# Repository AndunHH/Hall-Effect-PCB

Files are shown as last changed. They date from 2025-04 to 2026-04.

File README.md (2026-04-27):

# Hall-Effect-PCB
Repo to store PCB files for the hall effect sensor space mouse 

This repo is based on the work by Michael Roth:
https://www.printables.com/model/1063960-cad-mouse-spacemouse-using-hall-effect-sensors-w-p

Open the file in KiCad.

## Modifications
Added connectors for possible connection of keys, encoders and LEDs. The actual housing do not fit in a close space mouse, but it's fine for a first test or to solder the wires directly. 

Here a 3d rendering:

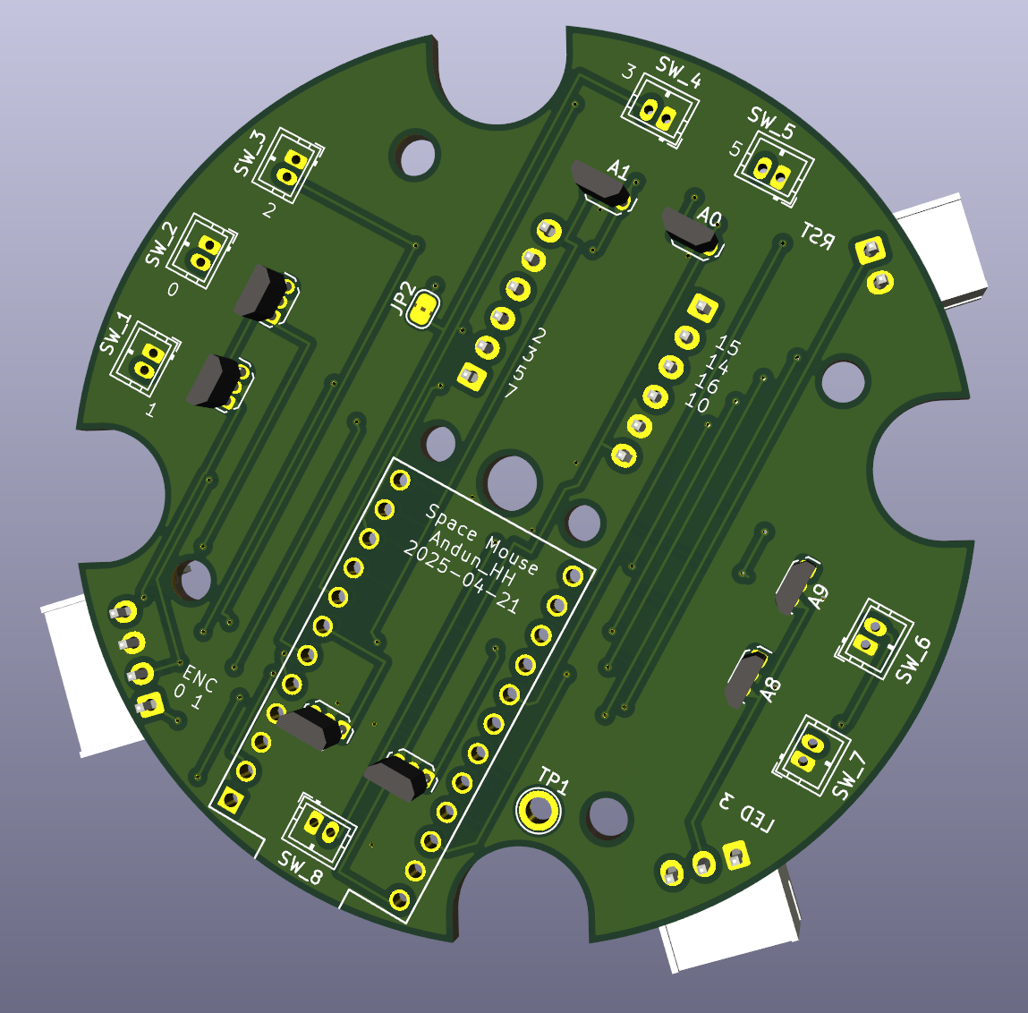
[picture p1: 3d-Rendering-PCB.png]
3d rendering


Here are the [STEP files](pcb.step) for the PCB itself.

Here a picture of the soldered PCB:
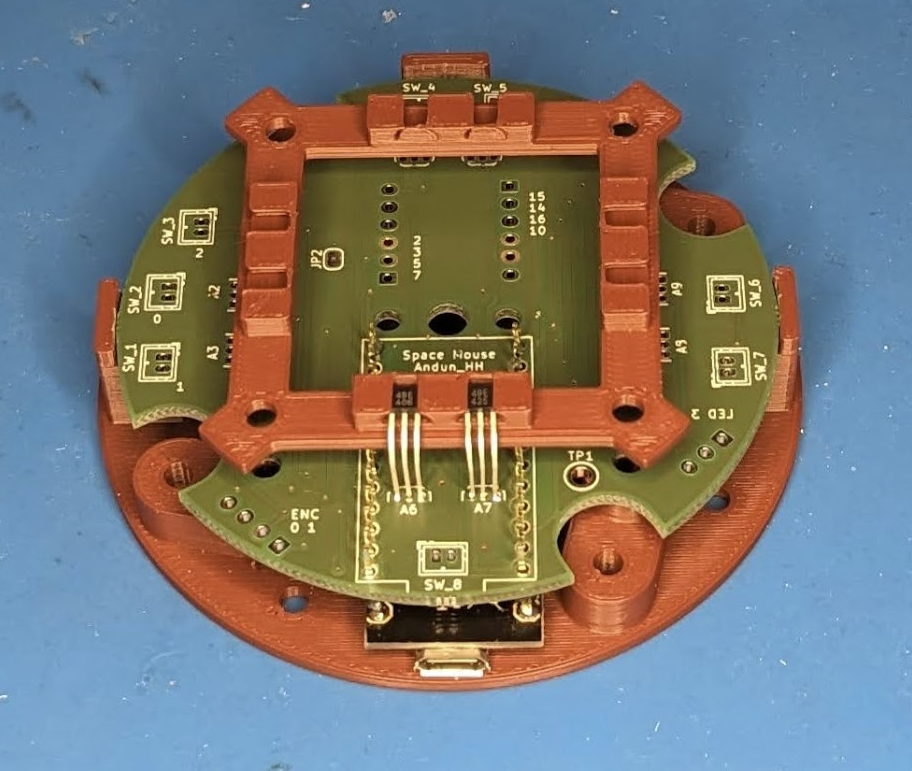
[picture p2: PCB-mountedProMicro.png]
Mounted PCB


### Key Connector 1
16, 14, 15, 10 + GND + VCC 

### Key Connector 2
5, 7, 2, 3 + GND + VCC
(3 is doubled with LED!) -> solder connection point

### Encoder
VCC, GND, 0, 1

### LED strip
GND, VCC, 3  (3 is doubled with key!) -> solder connection point

# Part Library
This project uses the arduino pro micro KiCad part library by Biacco42:

https://github.com/Biacco42/ProMicroKiCad

Therefore it is included as a git submodul.

Please run `git submodule update --init` after cloning this repo in order to populate the folder on your disk.

# Create your own part

I strongly advise, that you open the part in the newest version of KiCad for yourself and check the designs. I used the plugin by Aisler to publish the files directly to their manufacturing service. The provided gerber files are therefore __untested__! 

[Gerber Files V1.zip](pcb/HallEffectPCB-v1-gerbers.zip)

Use them at your own risk!

Probably more resilient are those [ODB files](pcb/HallEffectPCB-v1-odb.zip).

# License 
Creative Commons License  

This work is licensed under a Creative Commons (4.0 International License)

Attribution—Noncommercial—Share Alike

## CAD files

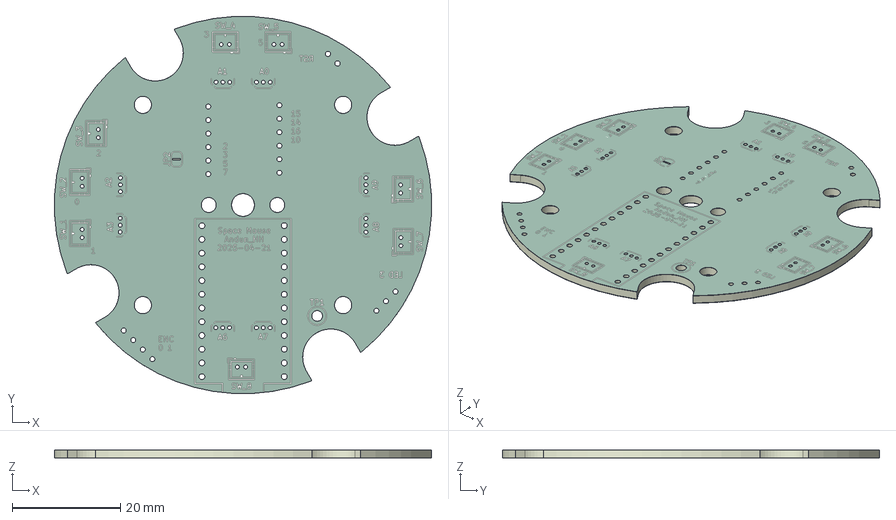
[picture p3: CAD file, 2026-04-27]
pcb.step
69.8 x 69.8 x 1.66 mm
Cad Mouse Pro PCB_silkscreen x 2
Cad Mouse Pro PCB_soldermask x 2
Cad Mouse Pro PCB_PCB

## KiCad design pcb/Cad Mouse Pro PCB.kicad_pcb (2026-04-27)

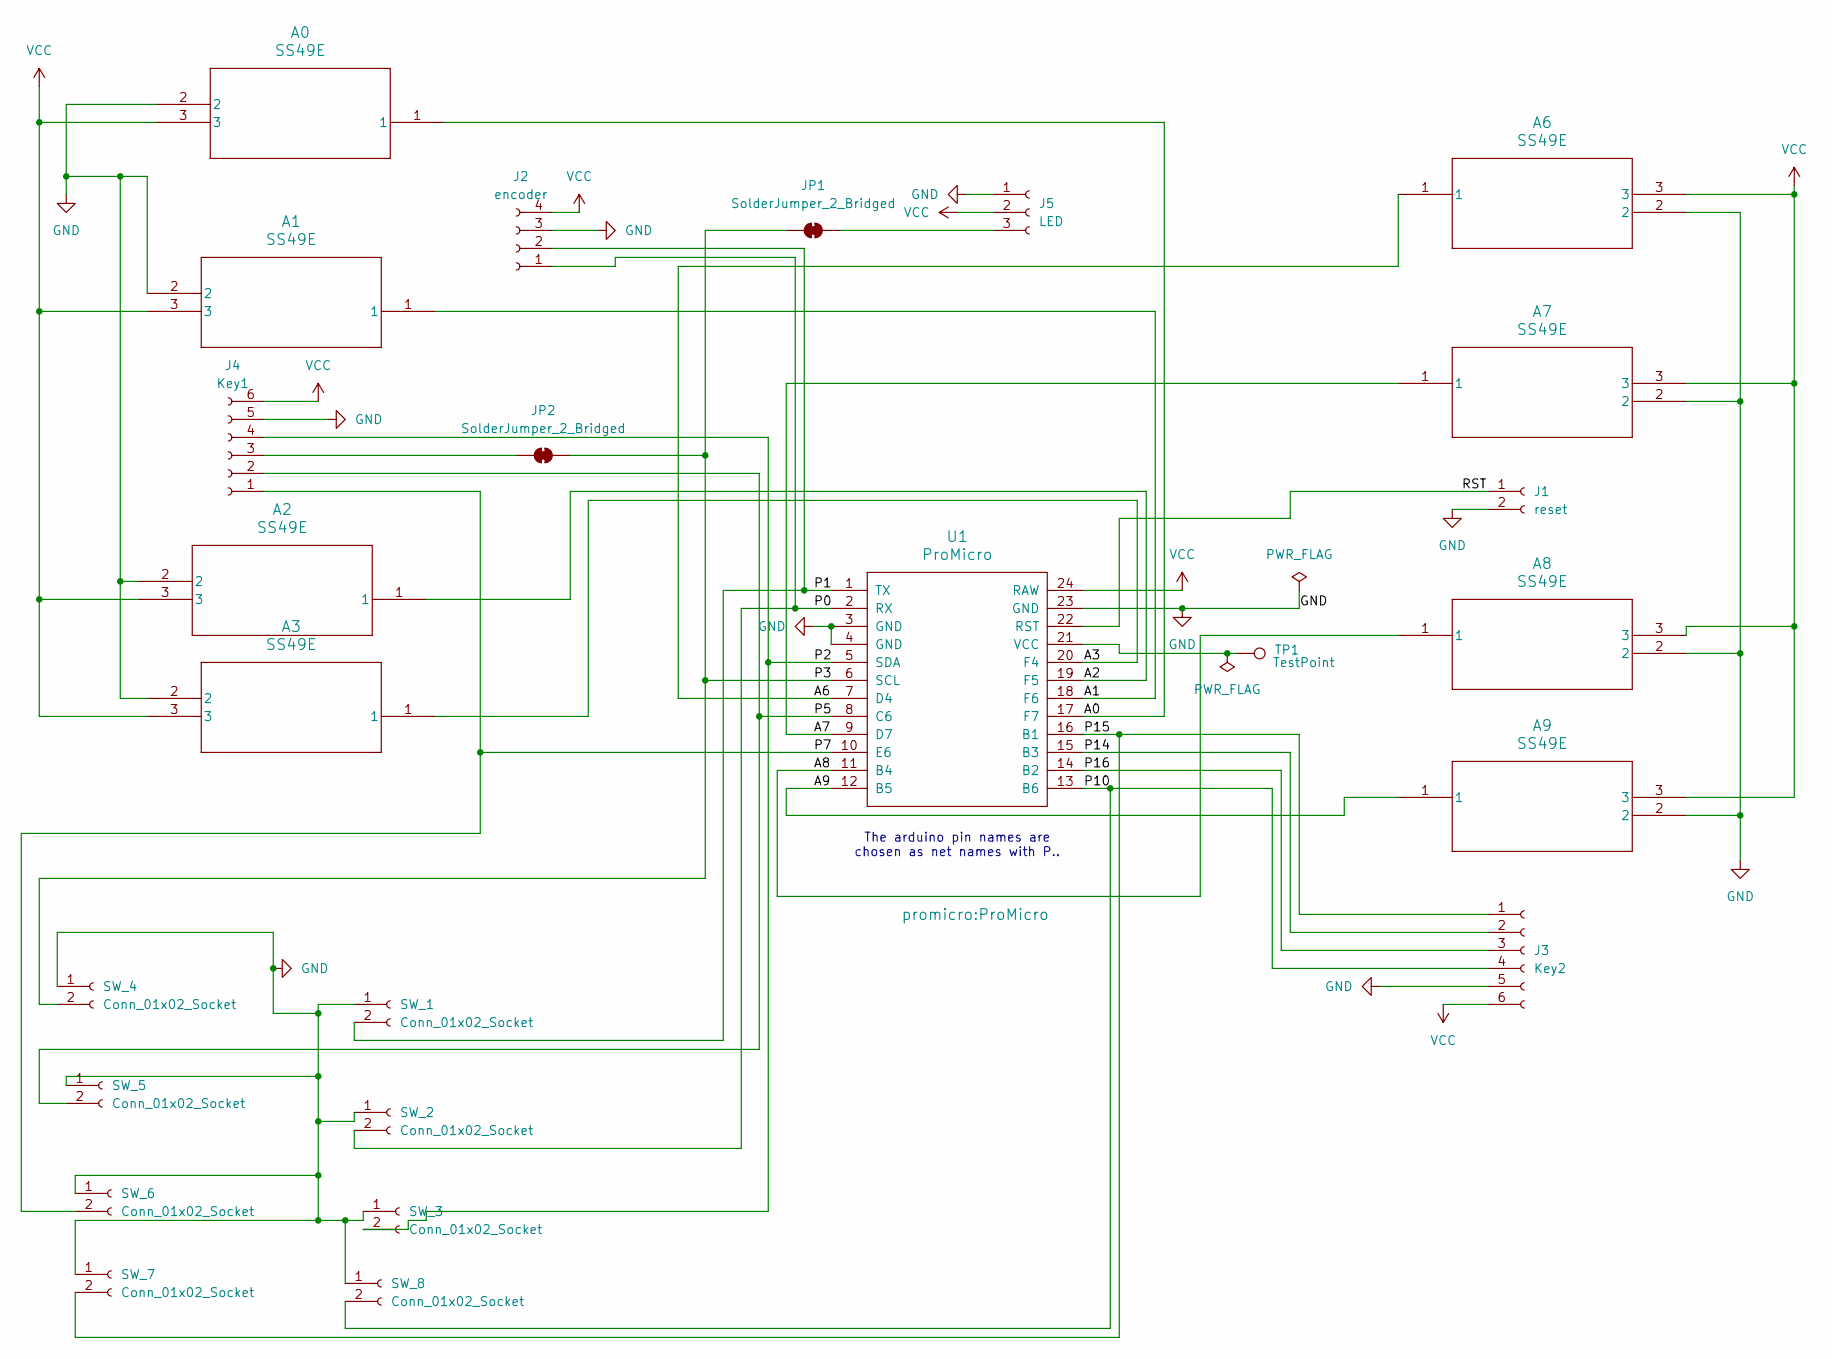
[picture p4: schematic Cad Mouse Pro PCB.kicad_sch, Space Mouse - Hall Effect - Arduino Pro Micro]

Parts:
A0, A1, A2, A3, A6, A7, A8, A9: SS49E; TO-92Flat
J1: reset; JST_XH_S2B-XH-A-1_1x02_P2.50mm_Horizontal
J2: encoder; JST_XH_S4B-XH-A-1_1x04_P2.50mm_Horizontal
J3: Key2; JST_XH_S6B-XH-A-1_1x06_P2.50mm_Horizontal
J4: Key1; JST_XH_S6B-XH-A-1_1x06_P2.50mm_Horizontal
J5: LED; JST_XH_S3B-XH-A-1_1x03_P2.50mm_Horizontal
JP1, JP2: SolderJumper_2_Bridged; SolderJumper-2_P1.3mm_Bridged2Bar_RoundedPad1.0x1.5mm
SW_1, SW_2, SW_3, SW_4, SW_5, SW_6, SW_7, SW_8: Conn_01x02_Socket; JST_ZH_B2B-ZR_1x02_P1.50mm_Vertical
TP1: TestPoint; TestPoint_Plated_Hole_D2.0mm
U1: ProMicro

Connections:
/A0: A0.1, U1.17 (F7)
/A1: A1.1, U1.18 (F6)
/A2: A2.1, U1.19 (F5)
/A3: A3.1, U1.20 (F4)
/A6: A6.1, U1.7 (D4)
/A7: A7.1, U1.9 (D7)
/A8: A8.1, U1.11 (B4)
/A9: A9.1, U1.12 (B5)
/P0: J2.1, SW_2.2, U1.2 (RX)
/P1: J2.2, SW_1.2, U1.1 (TX)
/P2: J4.4, SW_3.2, U1.5 (SDA)
/P3: JP1.2 (B), JP2.1 (A), SW_4.2, U1.6 (SCL)
/P5: J4.2, SW_5.2, U1.8 (C6)
/P7: J4.1, SW_6.2, U1.10 (E6)
/P10: J3.4, SW_8.2, U1.13 (B6)
/P14: J3.2, U1.15 (B3)
/P15: J3.1, SW_7.2, U1.16 (B1)
/P16: J3.3, U1.14 (B2)
/RST: J1.1, U1.22 (RST)
GND: A0.2, A1.2, A2.2, A3.2, A6.2, A7.2, A8.2, A9.2, J1.2, J2.3, J3.5, J4.5, J5.1, SW_1.1, SW_2.1, SW_3.1, SW_4.1, SW_5.1, SW_6.1, SW_7.1, SW_8.1, U1.3 (GND), U1.4 (GND), U1.23 (GND)
unnamed: J4.3, JP2.2 (B)
unnamed: J5.3, JP1.1 (A)
unnamed: TP1.1 (1_1), U1.21 (VCC)
VCC: A0.3, A1.3, A2.3, A3.3, A6.3, A7.3, A8.3, A9.3, J2.4, J3.6, J4.6, J5.2, U1.24 (RAW)

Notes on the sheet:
The arduino pin names are chosen as net names with P..

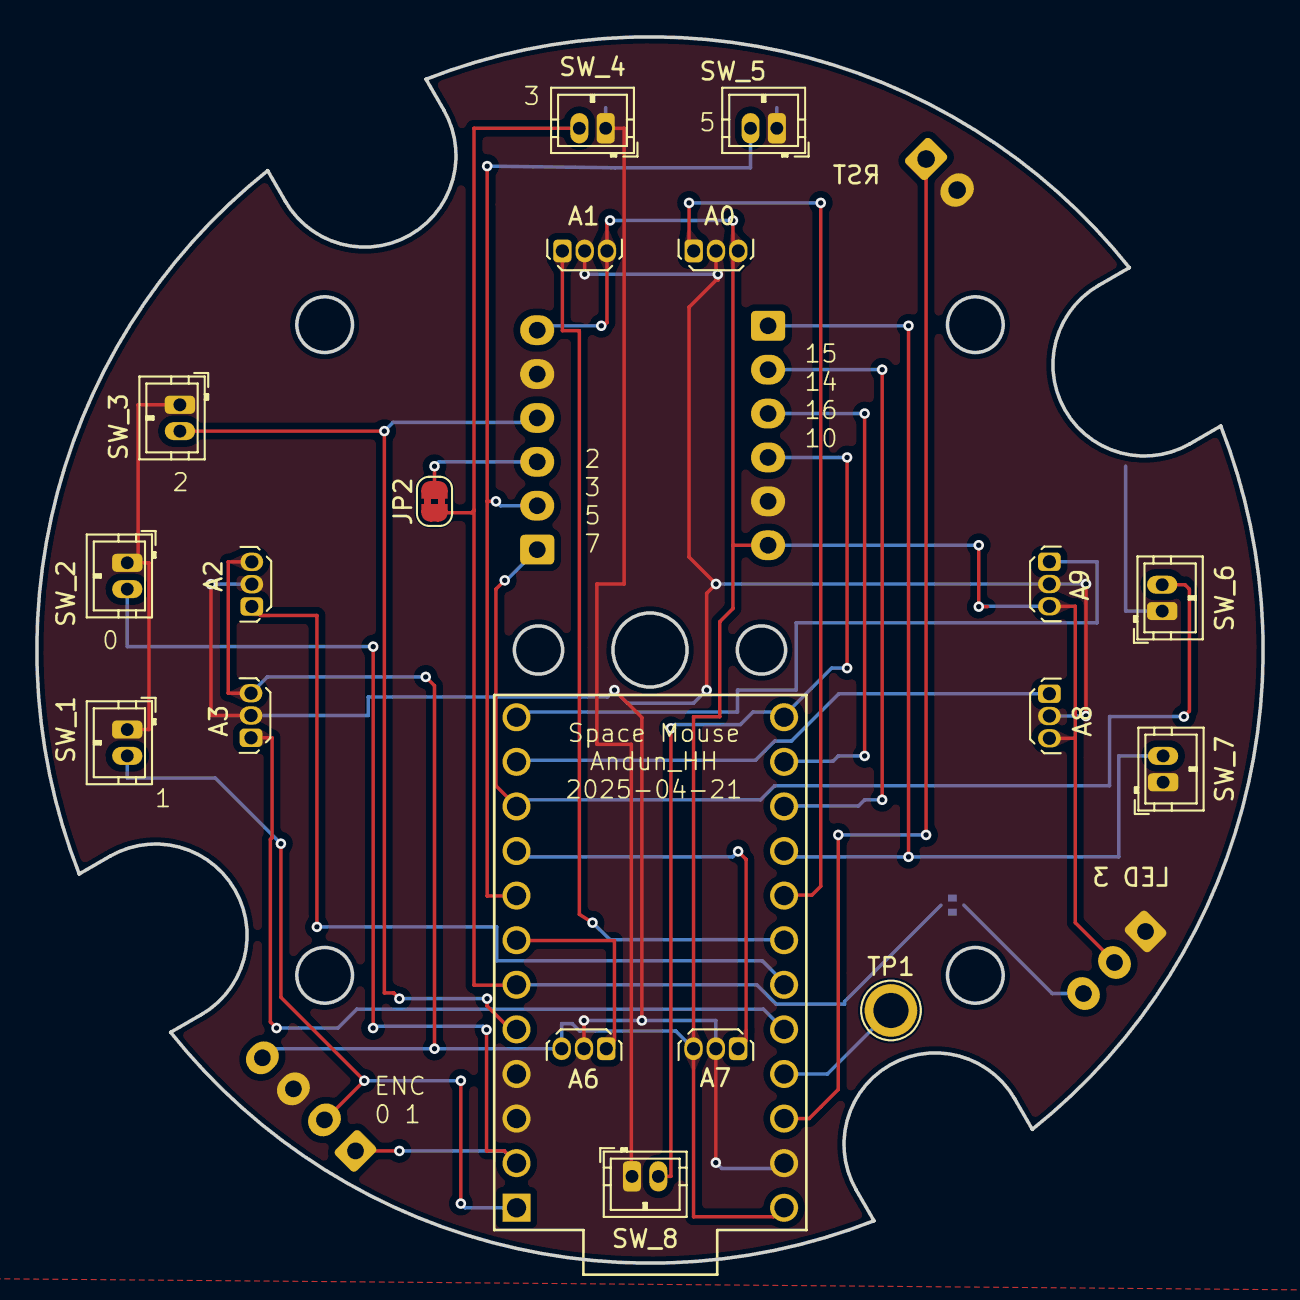
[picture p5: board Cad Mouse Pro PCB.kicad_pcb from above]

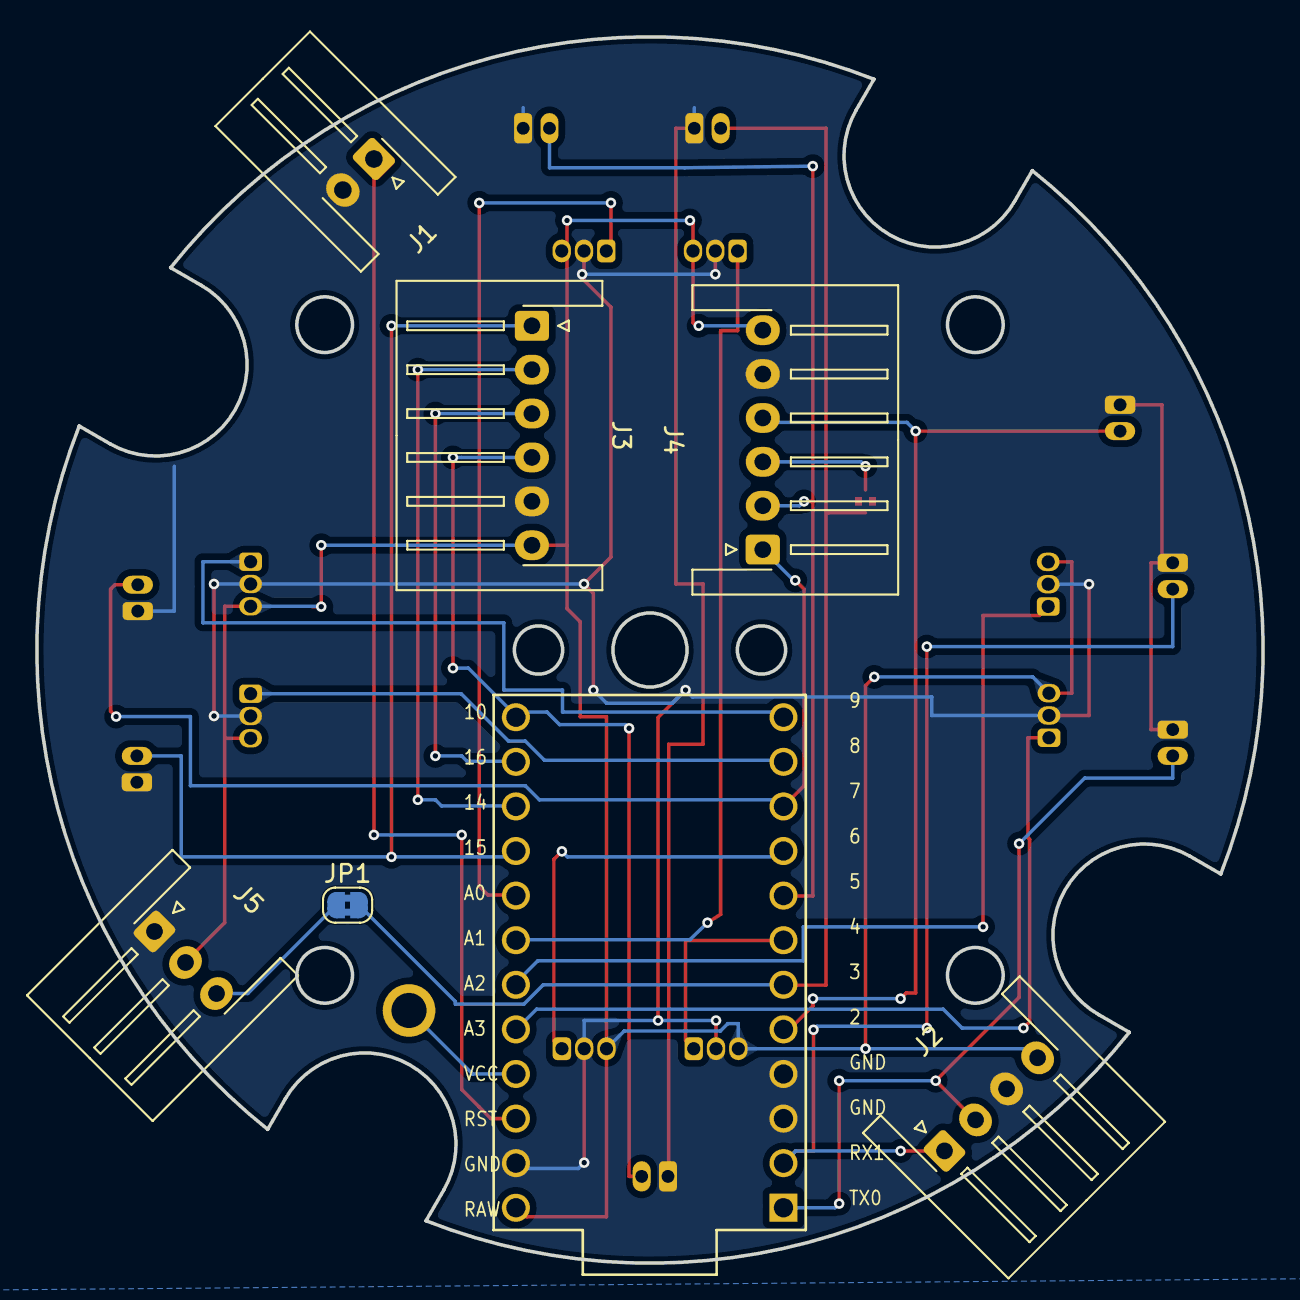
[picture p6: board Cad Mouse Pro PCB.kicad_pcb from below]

Board: 2 copper layers, 69.8 x 69.8 mm, 25 parts (7 on the bottom side), 24 nets.

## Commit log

2025-04-20 Init with M.Roths PCB
    [CAD MOUSE PCB Pro.kicad_sch, Cad Mouse Pro PCB.dsn, Cad Mouse Pro PCB.kicad_pcb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]
2025-04-21 Added pro micro submodul and connectors for debugging
    [Cad Mouse Pro PCB.kicad_pcb, Cad Mouse Pro PCB.kicad_sch]
2025-04-21 removed old files
    [CAD MOUSE PCB Pro.kicad_sch, Cad Mouse Pro PCB.dsn]
2026-04-25 include odb and gerber files. untested!
    [Cad Mouse Pro PCB.kicad_pcb, pcb.step]
